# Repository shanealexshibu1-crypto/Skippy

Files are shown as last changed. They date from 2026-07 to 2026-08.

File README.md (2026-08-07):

# Skippy

A fully custom mechanical keyboard designed for mac from the ground up, including the PCB, and 3D-printed case. This project combines electronics and mechanical design to create a unique ergonomic keyboard.

## Features

+ Custom PCB designed in KiCad

+ RP2040-based controller

+ QMK Firmware support

+ Hot-swappable mechanical switches

+ Custom 3D-printed case

+ Custom switch plate design

+ Rotary encoder for media controls

+ OLED display for custom information display

+ RGB lighting support

+ Designed for an ergonomic typing experience

## Design Tools

### Electronics

  + KiCad — PCB schematic and layout
  
### Mechanical Design

  + Fusion 360 — CAD modeling

## Hardware

  + Raspberry Pi Pico W RP2040 Development board
  + Outemu Yellow Jade Silent Switch 
  + EC11 15 mm Half Handle
  + 1.3" OLED SSH1106 128X64 I²C Communication (White)
  + SK6812 MINI-E RGB
  + Kailh Hot-Swap PCB Socket
  + White Steel Stabilizers (Plate Mount)
  + M2 screws (legth=4mm)
  + Threaded inserts (length=4.5mm)

## Firmware

The keyboard runs custom QMK firmware with the following features:

### RGB Lighting
+ Theme 1: RGB Off
+ Theme 2: White reactive ripple effect on key press
+ Theme 3: RGB rainbow loop animation
### OLED Display

The OLED displays the current Words Per Minute (WPM) using QMK's WPM feature, accompanied by a smooth wave animation.

Screenshot 2026-07-26 at 7 34 46 AM

### Rotary Encoder
+ Rotate clockwise: Increase system volume
+ Rotate counterclockwise: Decrease system volume
+ Press the encoder: Mute or unmute the system volume

### Firmware Compilation and Flashing

The firmware for Skippy is located in the `Firmware` folder. It contains the custom QMK files used for the keyboard, including:

- `keyboard.json`
- `config.h`
- `rules.mk`
- `keymap.c`

### Compiling

To compile the firmware, copy the `Firmware` folder into your local QMK `keyboards` directory and rename it to `skippy` if needed.

Then run:

```bash
qmk compile -kb skippy -km default
```

### Flashing

Since Skippy uses an RP2040, hold the **BOOTSEL** button while plugging the keyboard into your computer. A drive named **RPI-RP2** will appear. Copy the generated `.uf2` file onto the drive, and the keyboard will automatically reboot with the new firmware.

## Gallery

#### Image from Keyboard Layout Editor

Screenshot 2026-07-10 at 1 04 09 AM

#### PCB Schematic

Screenshot 2026-07-10 at 1 02 39 AM

#### Final PCB

Screenshot 2026-07-10 at 1 02 55 AM

#### Final PCB 3D Model with all the Components 

Screenshot 2026-07-10 at 12 31 56 AM

#### Plate 3D Model

Screenshot 2026-07-10 at 1 04 48 AM

#### 3D Model of the Case

Screenshot 2026-07-10 at 1 05 00 AM

#### Final Render

Render

## BOM
## Bill of Materials (BOM)

| Part | Qty | PCS per Qty | Manufacturer | Cost (USD) | Cost (AED) | Purchase Link | Purchase Place |
|---|---:|---:|---|---:|---:|---|---|
| Custom Keyboard PCB | 5 | 1 | JLCPCB | $24.50 | AED 89.98 | — | JLCPCB |
| Bottom Case (9600 Resin) | 1 | 1 | JLC3DP | $24.31 | AED 89.28 | — | JLC3DP |
| Top Plate (9600 Resin) | 1 | 1 | JLC3DP | $9.42 | AED 34.59 | — | JLC3DP |
| Outemu Yellow Jade Silent Switches | 1 | 80 | JHSD | $21.34 | AED 78.38 | [link](https://ar.aliexpress.com/item/1005011633066141.html) | AliExpress |
| KBDiy Retro Mac Keycaps | 1 | 138 | KBDiy | $24.81 | AED 91.11 | [link](https://ar.aliexpress.com/item/1005008405001968.html) | AliExpress |
| Kailh Hot-swap Sockets | 1 | 100 | Kailh | $7.08 | AED 26.00 | [link](https://ar.aliexpress.com/item/1005009594313632.html) | AliExpress |
| Silicone Feet | 1 | 4 | Generic | $2.43 | AED 8.94 | [link](https://ar.aliexpress.com/item/1005012049221237.html) | AliExpress |
| Plate Mount Stabilizers | 1 | 5 | iTLY | $2.42 | AED 8.89 | [link](https://ar.aliexpress.com/item/1005010775921825.html) | AliExpress |
| EC11 Rotary Encoder | 1 | 5 | Generic | $5.69 | AED 20.89 | [link](https://ar.aliexpress.com/item/1005008716778661.html) | AliExpress |
| Aluminum Knob | 1 | 1 | Generic | $3.34 | AED 12.28 | [link](https://ar.aliexpress.com/item/1005008625986032.html) | AliExpress |
| M2×4 Screws | 1 | 50 | Generic | $1.26 | AED 4.64 | [link](https://ar.aliexpress.com/item/1005005618746295.html) | AliExpress |
| M2 Heat Inserts | 1 | 100 | Generic | $1.02 | AED 3.75 | [link](https://ar.aliexpress.com/item/1005008897571758.html) | AliExpress |
| 1.3" SSH1106 OLED | 1 | 1 | Generic | $4.29 | AED 15.74 | [link](https://ar.aliexpress.com/item/1005007499971422.html) | AliExpress |
| RP2040 Pico Type-C | 1 | 1 | RP2040 | $3.21 | AED 11.79 | [link](https://ar.aliexpress.com/item/1005008948799927.html) | AliExpress |
| SK6812 MINI-E LEDs | 1 | 100 | SK6812 | $6.98 | AED 25.63 | [link](https://ar.aliexpress.com/item/1005005193716172.html) | AliExpress |
| 1N4148 High-Speed Switching Diodes | 1 | 100 | TRIARK | $1.02 | AED 3.75 | [link](https://ar.aliexpress.com/item/1005009379098965.html) | AliExpress |

### Cost

| | USD | AED |
|---|---:|---:|
| Parts Total | $142.10 | AED 521.89 |
| JLCPCB Shipping | $48.00 | AED 176.28 |
| **Grand Total** | **$190.10** | **AED 698.17** |

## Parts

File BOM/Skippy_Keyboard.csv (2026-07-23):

Part | Qty | PCS per Qty | Manufacturer | Original Currency | Original Cost | Cost (USD) | Cost (AED) | Product link | Purchase Place
Custom Keyboard PCB (5 pcs) | 5 | 1 | JLCPCB | USD | 24.5 | 24.5 | 89.98 |  | JLC PCB
Bottom Case (9600 Resin) | 1 | 1 | JLC3DP | USD | 24.31 | 24.31 | 89.28 |  | JLC 3DP
Top Plate (9600 Resin) | 1 | 1 | JLC3DP | USD | 9.42 | 9.42 | 34.59 |  | JLC 3DP
Outemu Yellow Jade Silent Switches (80 pcs) | 1 | 80 | JHSD | AED | 78.38 | 21.34 | 78.38 | https://ar.aliexpress.com/item/1005011633066141.html?mp=1 | Ali Express
KBDiy Retro Mac Keycaps | 1 | 138 | KBDiy | AED | 91.11 | 24.81 | 91.11 | https://ar.aliexpress.com/item/1005008405001968.html?mp=1 | Ali Express
Kailh Hot-swap Sockets | 1 | 100 | Kailh | AED | 26 | 7.08 | 26 | https://ar.aliexpress.com/item/1005009594313632.html?mp=1 | Ali Express
Silicone Feet | 1 | 4 | Generic | AED | 8.94 | 2.43 | 8.94 | https://ar.aliexpress.com/item/1005012049221237.html?mp=1 | Ali Express
Plate Mount Stabilizers | 1 | 5 | iTLY | AED | 8.89 | 2.42 | 8.89 | https://ar.aliexpress.com/item/1005010775921825.html?mp=1 | Ali Express
EC11 Rotary Encoder | 1 | 5 | Generic | AED | 20.89 | 5.69 | 20.89 | https://ar.aliexpress.com/item/1005008716778661.html?mp=1 | Ali Express
Aluminum Knob | 1 | 1 | Generic | AED | 12.28 | 3.34 | 12.28 | https://ar.aliexpress.com/item/1005008625986032.html?mp=1 | Ali Express
M2x4 Screws | 1 | 50 | Generic | AED | 4.64 | 1.26 | 4.64 | https://ar.aliexpress.com/item/1005005618746295.html?mp=1 | Ali Express
M2 Heat Inserts | 1 | 100 | Generic | AED | 3.75 | 1.02 | 3.75 | https://ar.aliexpress.com/item/1005008897571758.html?mp=1 | Ali Express
1.3in SSH1106 OLED | 1 | 1 | Generic | AED | 15.74 | 4.29 | 15.74 | https://ar.aliexpress.com/item/1005007499971422.html?mp=1 | Ali Express
RP2040 Pico Type-C | 1 | 1 | RP2040 | AED | 11.79 | 3.21 | 11.79 | https://ar.aliexpress.com/item/1005008948799927.html?mp=1 | Ali Express
SK6812 MINI-E LEDs (100) | 1 | 100 | SK6812 | AED | 25.63 | 6.98 | 25.63 | https://ar.aliexpress.com/item/1005005193716172.html?mp=1 | Ali Express
IN4148 High-speed switching diodes | 1 | 100 | TRIARK | AED | 3.75 | 1.02 | 3.75 | https://ar.aliexpress.com/item/1005009379098965.html?curPageLogUid=wKenNV640iM4 | Ali Express
 |  |  |  | TOTAL |  | 142.1 | 521.89
 |  |  |  | SHIPPING (JLCPCB) | USD 48.00 | 48 | 176.28
 |  |  |  | GRAND TOTAL |  | 190.1 | 698.17

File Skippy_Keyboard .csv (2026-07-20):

Part | Qty | Manufacturer | Original Currency | Original Cost | Cost (USD) | Cost (AED)
Custom Keyboard PCB (5 pcs) | 5 | JLCPCB | USD | 24.5 | 24.5 | 89.98
Bottom Case (9600 Resin) | 1 | JLC3DP | USD | 24.31 | 24.31 | 89.28
Top Plate (9600 Resin) | 1 | JLC3DP | USD | 9.42 | 9.42 | 34.59
Outemu Yellow Jade Silent Switches (80 pcs) | 80 | JHSD | AED | 78.38 | 21.34 | 78.38
KBDiy Retro Mac Keycaps | 1 | KBDiy | AED | 91.11 | 24.81 | 91.11
Kailh Hot-swap Sockets (100) | 100 | Kailh | AED | 26 | 7.08 | 26
Silicone Feet | 4 | Generic | AED | 8.94 | 2.43 | 8.94
Plate Mount Stabilizers | 5 | iTLY | AED | 8.89 | 2.42 | 8.89
EC11 Rotary Encoder | 1 | Generic | AED | 20.89 | 5.69 | 20.89
Aluminum Knob | 1 | Generic | AED | 12.28 | 3.34 | 12.28
M2x4 Screws | 50 | Generic | AED | 4.64 | 1.26 | 4.64
M2 Heat Inserts | 100 | Generic | AED | 3.75 | 1.02 | 3.75
1.3in SSH1106 OLED | 1 | Generic | AED | 15.74 | 4.29 | 15.74
RP2040 Pico Type-C | 1 | RP2040 | AED | 11.79 | 3.21 | 11.79
SK6812 MINI-E LEDs (100) | 100 | SK6812 | AED | 25.63 | 6.98 | 25.63
 |  |  | TOTAL |  | 142.1 | 521.89
 |  |  | SHIPPING (JLCPCB) | USD 48.00 | 48 | 176.28
 |  |  | GRAND TOTAL |  | 190.1 | 698.17

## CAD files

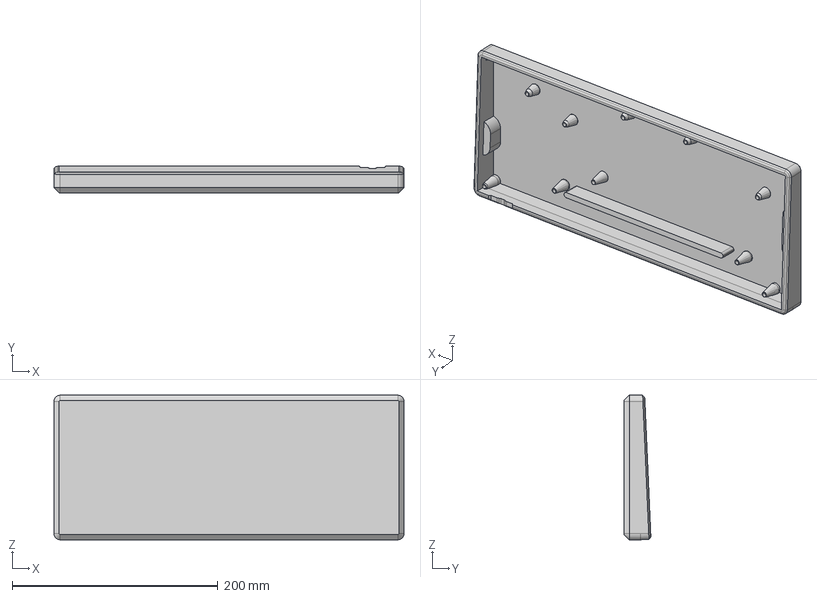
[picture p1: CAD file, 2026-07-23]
CAD/CASE/case.step
340.0 x 26.0 x 140.4 mm

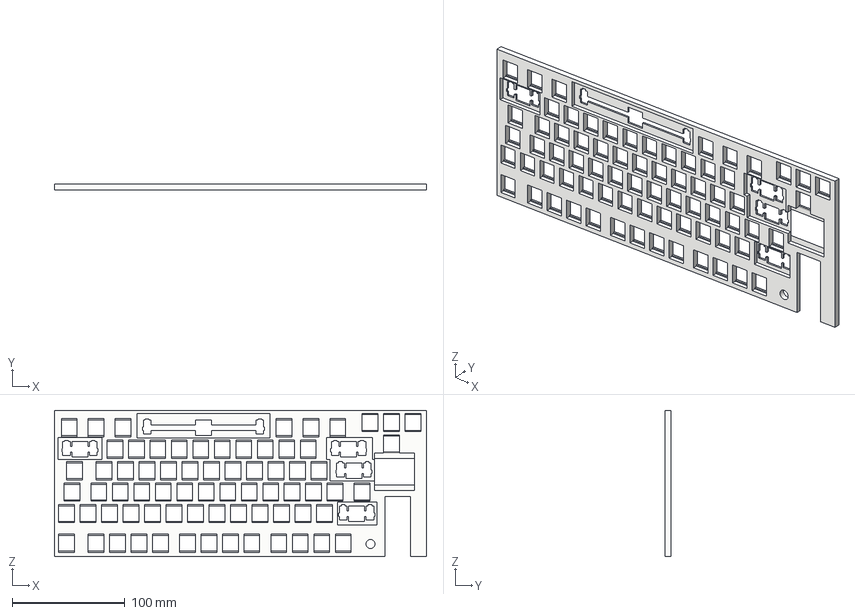
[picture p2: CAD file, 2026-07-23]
CAD/Top_Plate/Top plate.step
329.8 x 5.00 x 129.8 mm

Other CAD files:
CAD/Assembled keyboard/Assembly.f3z
CAD/CASE/case.stl
CAD/Top_Plate/Top plate.stl

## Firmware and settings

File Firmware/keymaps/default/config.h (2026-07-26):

#pragma once


#define OLED_DISPLAY_128X64
#define OLED_TIMEOUT 0          
#define OLED_UPDATE_INTERVAL 16  


#define RGB_MATRIX_LED_COUNT 77
#define RGB_MATRIX_DEFAULT_MODE RGB_MATRIX_SOLID_COLOR
#define RGB_MATRIX_KEYPRESSES         
#define RGB_MATRIX_FRAMEBUFFER_EFFECTS
#define ENABLE_RGB_MATRIX_SOLID_COLOR
#define ENABLE_RGB_MATRIX_SPLASH
#define ENABLE_RGB_MATRIX_CYCLE_ALL
#define RGB_MATRIX_MAXIMUM_BRIGHTNESS 180
#define RGB_MATRIX_SPLASH_SPEED_MAX 200 


#define COMBO_COUNT 1

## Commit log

2026-07-09 Rename skippy 2.kicad_pcb to PCB/skippy 2.kicad_pcb
    [skippy 2.kicad_pcb]
2026-07-09 Rename skippy 2.kicad_pro to PCB/skippy 2.kicad_pro
2026-07-09 Rename skippy 2.kicad_sch to PCB/skippy 2.kicad_sch
    [skippy 2.kicad_sch]
2026-07-20 Rename Skippy_Keyboard .csv to BOM/Skippy_Keyboard .csv
    [Skippy_Keyboard .csv]
